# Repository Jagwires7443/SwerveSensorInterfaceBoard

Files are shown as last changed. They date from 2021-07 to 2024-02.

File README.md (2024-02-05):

# SwerveSensorInterfaceBoard
Board to Interface an SRX MAG ENCODER to a SPARK MAX and a roboRIO

This small board (2.0" x 0.7") interfaces an SRX MAG ENCODER to a SPARK MAX (A/B incremental encoder inputs plus PWM absolute encoder input, although the latter is not yet supported by SPARK MAX) and to the roboRIO (PWM absolute encoder input used with a digital input; in software used with DutyCycle or DutyCycleEncoder).  The sensor is powered by the motor controller, and the roboRIO is properly isolated.  This is a good starting point for similar interface projects in the FRC (FIRST Robotics Competition) ecosystem.

These are the [KiCad](https://www.kicad.org/) design files, including schematic symbols, PCB footprints, and 3-D models for all the components.

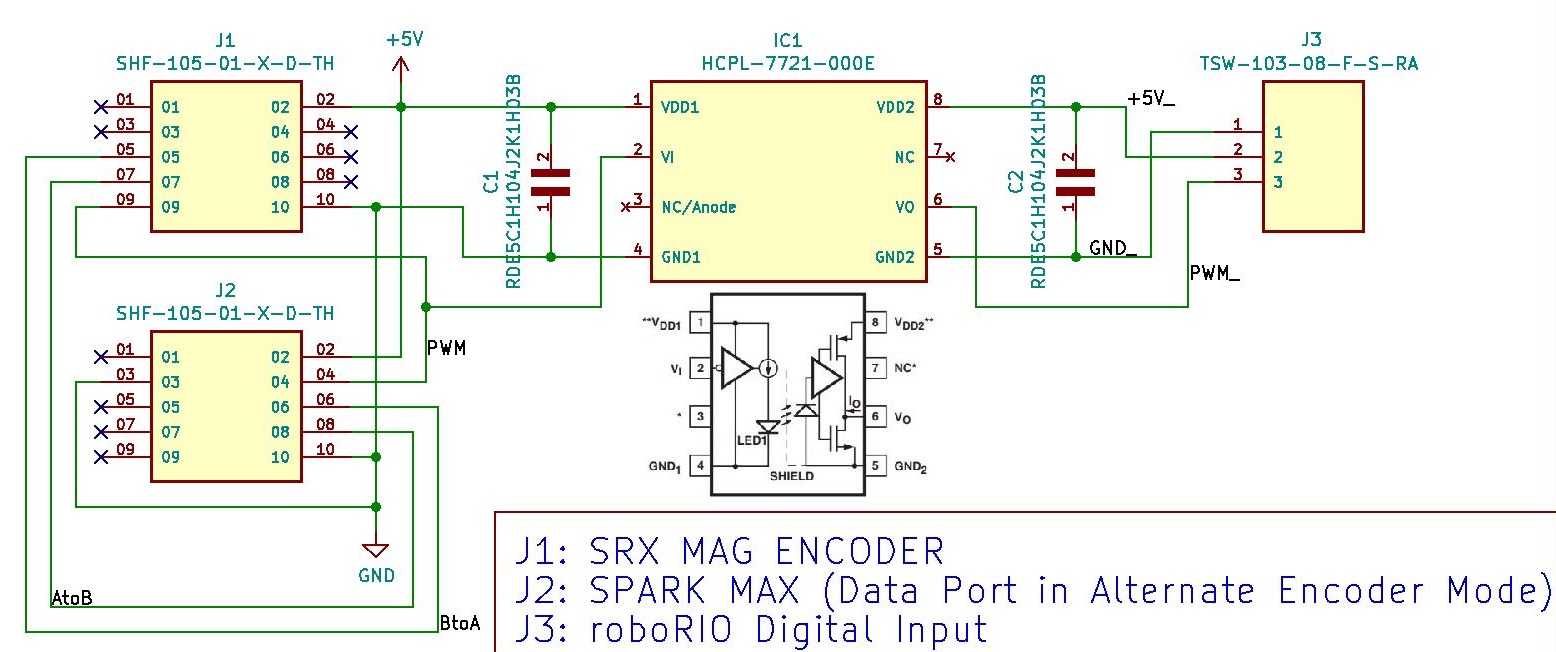
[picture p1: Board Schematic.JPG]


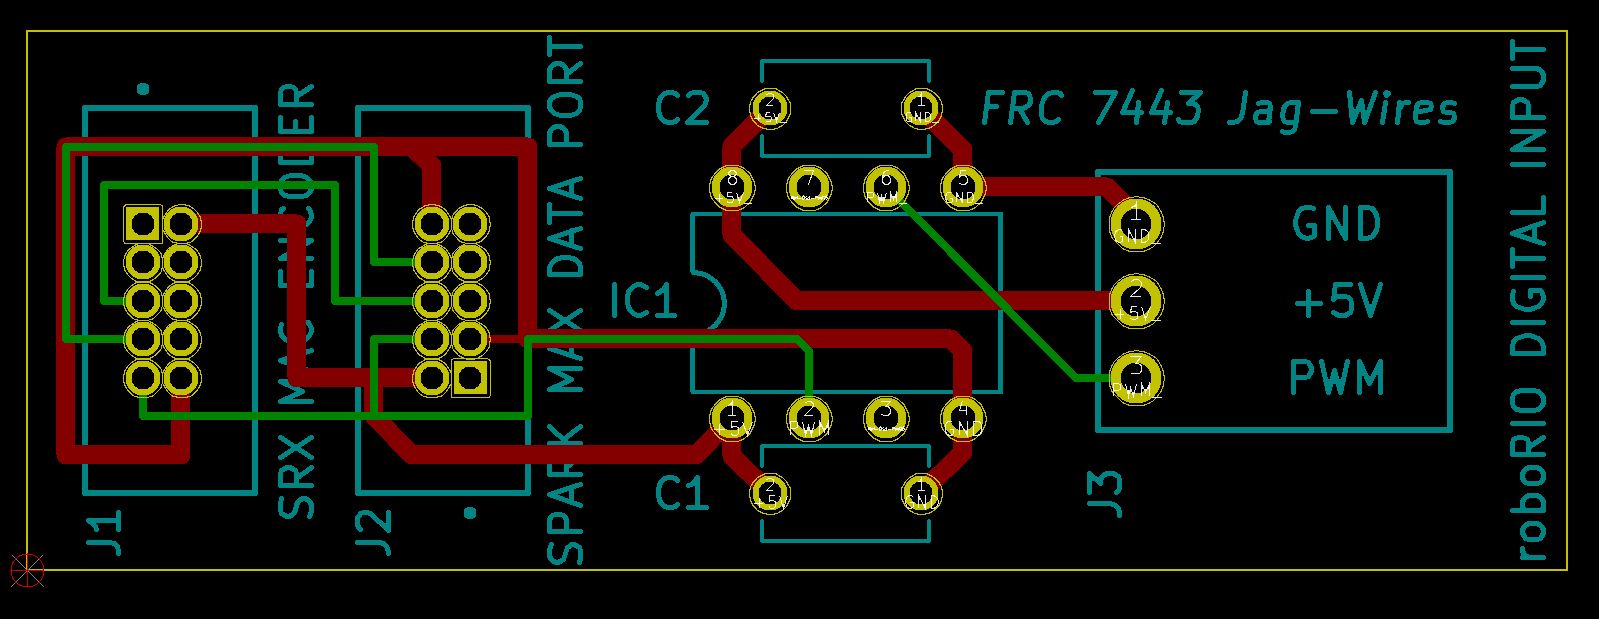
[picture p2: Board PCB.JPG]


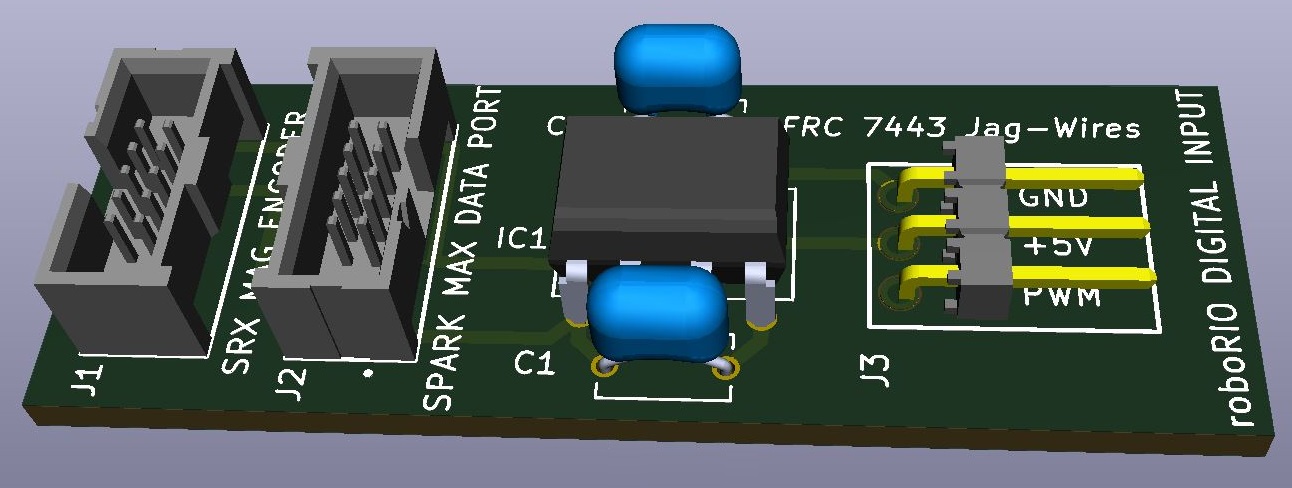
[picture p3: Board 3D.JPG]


***Note that a simpler way to handle this is to leave the SPARK MAX out of things and to simply connect pins 2 (+5V), 9 (PWM), and 10 (GND) from the SRX MAG ENCODER to a roboRIO digital input.  Indeed, until REV addresses [this](https://trello.com/c/bvnPPcZD/108-add-continuous-pid-capability) bug (fixed for 2023), there's not much point in trying to use the SPARK MAX to directly handle closed-loop control.  Here are links to parts (multiple suppliers) that are helpful with this approach:
[CABLE ASSEM .05" 10POS 3"](https://www.digikey.com/en/products/detail/samtec-inc/FFSD-05-D-03-00-01-N/2651110),
[10-pin 2x5 Socket-Socket 1.27mm IDC (SWD) Cable - 150mm long](https://www.adafruit.com/product/1675),
[SRX / Gadgeteer Data Cable (4-pack)](https://newsite.ctr-electronics.com/srx-gadgeteer-data-cable-4-pack/),
[Talon SRX / Spark Max - 10 Pin Data Cable](https://www.andymark.com/products/talon-srx-hero-10-pin-data-cable),
[SWD (2x5 1.27mm) Cable Breakout Board](https://www.adafruit.com/product/2743),
[Gadgeteer Breakout Module (5 Pack)](https://newsite.ctr-electronics.com/gadgeteer-breakout-module-5-pack/),
[SPARK MAX Data Port Breakout Board](https://www.revrobotics.com/rev-11-1278/).***

***Also note that REV now uses pin 6 of the SPARK MAX data port for the PWM absolute encoder input, so this part of the PCB desgn is also out-of-date.***

Working with the 0.05" headers and fine-pitch cables can be tough.  Test that the motor runs as expected before connecting to the SPARK MAX.  Then, be sure the SPARK MAX has been configured to "Alternate Encoder Mode" and this configuration has been saved.  At this point, connect to the SPARK MAX and verify that the LED on the SRX MAG ENCODER is on (any color, the color only depends on the distance to the magnet).  Be sure the LEDs on the SPARK MAX are as expected, and that you can still communicate with it via "REV Hardware Client".  If not, power down and start looking for shorts or opens -- likely trouble spots are the solder connections on the board and the points where the connectors and cables join.  At this point, power and ground are probably good.

Now, check that the motor still runs as expected.  It is possible to short signals which are essential for the motor to run, so suspect a problem in this area if the motor no longer runs well.  Even though these signals normally come in via the built-in signal cable from the (NEO) motor, these same connections are present at the "Data Port".  Trouble in this area may also cause a "Sensor Fault".  If things are all good so far, you can run the motor and should see changing values returned via GetPosition() and GetVelocity().  Finally, check the PWM absolute position signal using a DutyCycle object.  Code to do these things is [here](https://github.com/Jagwires7443/Swerve).  This code contains an extensive test mode (used with Shuffleboard) which will read and display all of the sensor data.

Another option for this type of board is to go surface mount.  The boards REV itself has created seem to use an [FLE-107-01-G-DV](https://www.samtec.com/products/fle-107-01-g-dv-a-tr) connector to directly plug into the SPARK MAX.  Note this is actually a 14-pin connector -- the outer 4 pins are not used to make a connection, but to help to take up some of the excess space on each side of the 10 pins on the connector that is part of the SPARK MAX.  The REV boards are shaped to match the outline of the end of the SPARK MAX where they plug in (roughly 1.16" wide by 0.75" to 0.90" tall, with a roughtly 0.14" by 0.25" notch on each side, roughly 0.14" from the top, with the connector centered roughly 0.18" below the bottom of the notch).

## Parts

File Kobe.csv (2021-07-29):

Quantity | Link | Designator(s) | Manufacturer | Part # | Supplier 1 | Part # | Supplier 2 | Part #
2 | https://www.samtec.com/products/shf-105-01-l-d-th | J1/2 | Samtec | SHF-105-01-L-D-TH | DigiKey | SAM10711-ND | Mouser | 200-SHF10501LDTH
2 | https://www.murata.com/en-us/products/productdetail?partno=RDE5C1H104J2K1H03B | C1/2 | Murata | RDE5C1H104J2K1H03B | DigiKey | 490-RDE5C1H104J2K1H03B-ND | Mouser | 81-RDE5C1H104J2K1H3B
1 | https://www.broadcom.com/products/optocouplers/industrial-plastic/digital-optocouplers/high-speed-cmos/hcpl-7721 | IC1 | Broadcom | HCPL-7721-000E | DigiKey | 516-1550-5-ND | Mouser | 630-HCPL-7721-000E
1 | https://www.samtec.com/products/tsw-103-08-f-s-ra | J3 | Samtec | TSW-103-08-F-S-RA | DigiKey |  | Mouser
1 |  | PCB | Custom | - |  | - |  | -
1 | Solder (Roll/Tube)
4 | 10-pin IDC Connector: https://www.samtec.com/products/ffsd-05-01-n |  | Samtec | FFSD-05-01-N | DigiKey | SAM10472-ND | Mouser | 200-FFSD0501N
2 | 10-conductor Ribbon Cable (2 lengths, cut from 1 longer length) |  | CNC Tech | 300-30-10-GR-0250F | DigiKey | 300-30-10-GR-0250F | Arrow | 300-30-10-GR-0250F
2 | 3-pin Molex Connector |  | Molex | 50579003 | DigiKey | WM2801-ND | Mouser | 50579003
6 | Molex Crimp Sockets (for use with connector above) |  | Molex | 16021124 | DigiKey | WM2573-ND | Mouser | 16021124
1 | PWM Cable
 | [Or: 2x premade 10-pin jumpers and 1x premade PWM cable]
1 | Heatshrink |  | 3M | FP-301 1" CR 100' | DigiKey | FP100C-3R0-ND | Mouser | FP-301 1 1/2" CR 100'

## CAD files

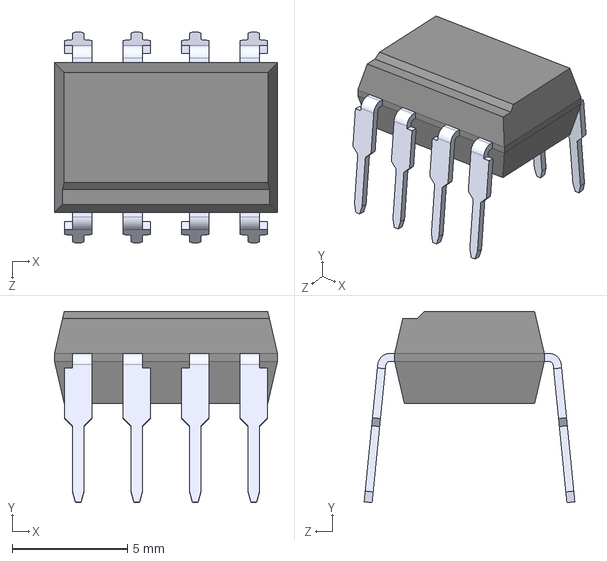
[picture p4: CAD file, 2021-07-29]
HCPL-7721-000E/HCPL-7721-000E.step
9.68 x 8.30 x 9.15 mm

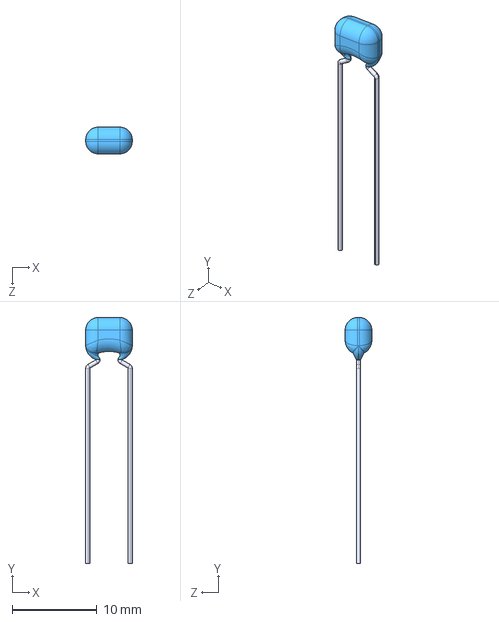
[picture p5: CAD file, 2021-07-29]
RDE5C1H104J2K1H03B/RDE5C1H104J2K1H03B.step
5.50 x 29.0 x 3.15 mm

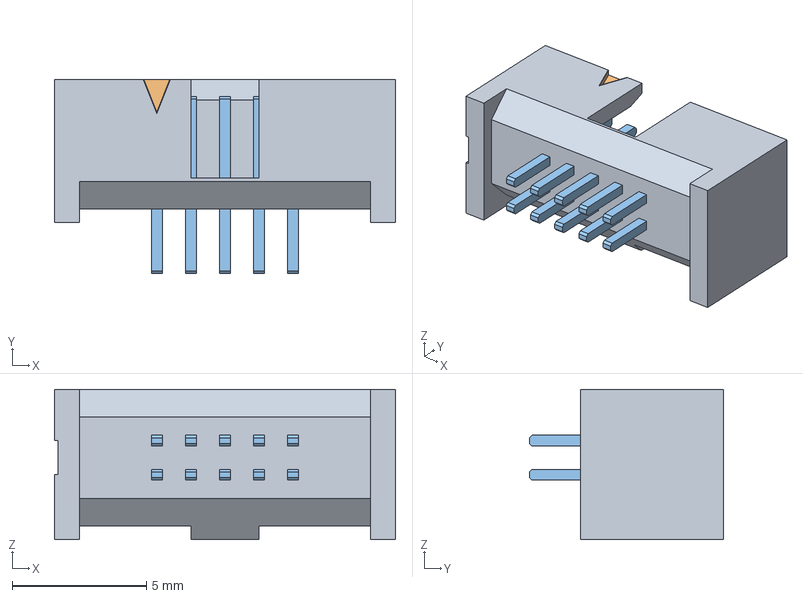
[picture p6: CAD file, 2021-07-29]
SHF-105-01-X-D-TH/SHF-105-01-X-D-TH.step
12.7 x 7.24 x 5.59 mm
_SHF-105-01-D_header
_SHF-First_Position_Indicator
_T-1S71-02-05-D-TH

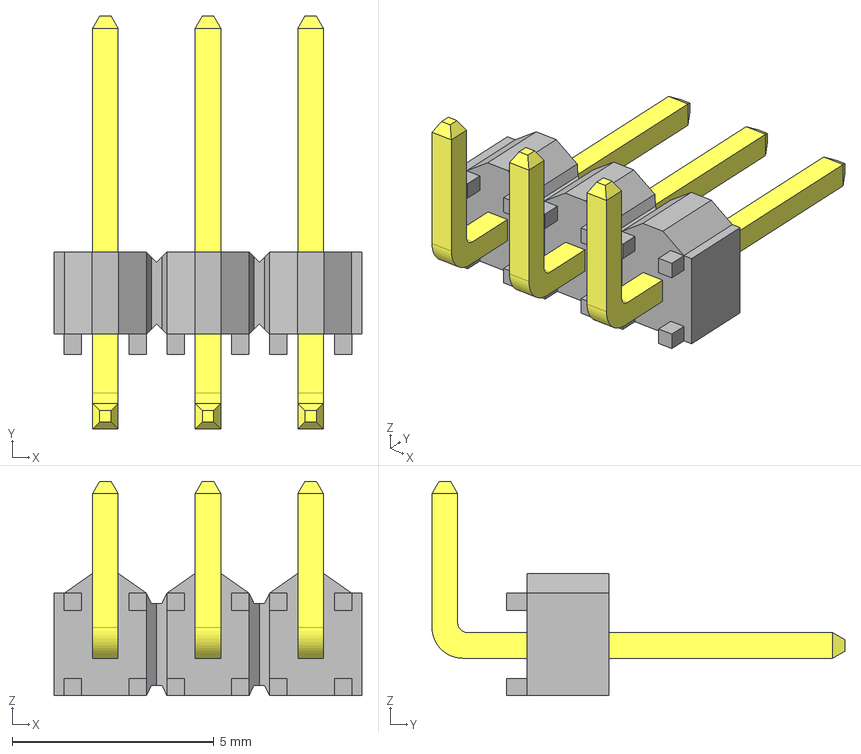
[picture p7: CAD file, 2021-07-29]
TSW-103-08-F-S-RA/TSW-103-08-F-S-RA.step
7.62 x 10.2 x 5.31 mm
_TSW-103-08-F-S-RA_body
_T-1S6-08-TSW-1-08-3-RA-S

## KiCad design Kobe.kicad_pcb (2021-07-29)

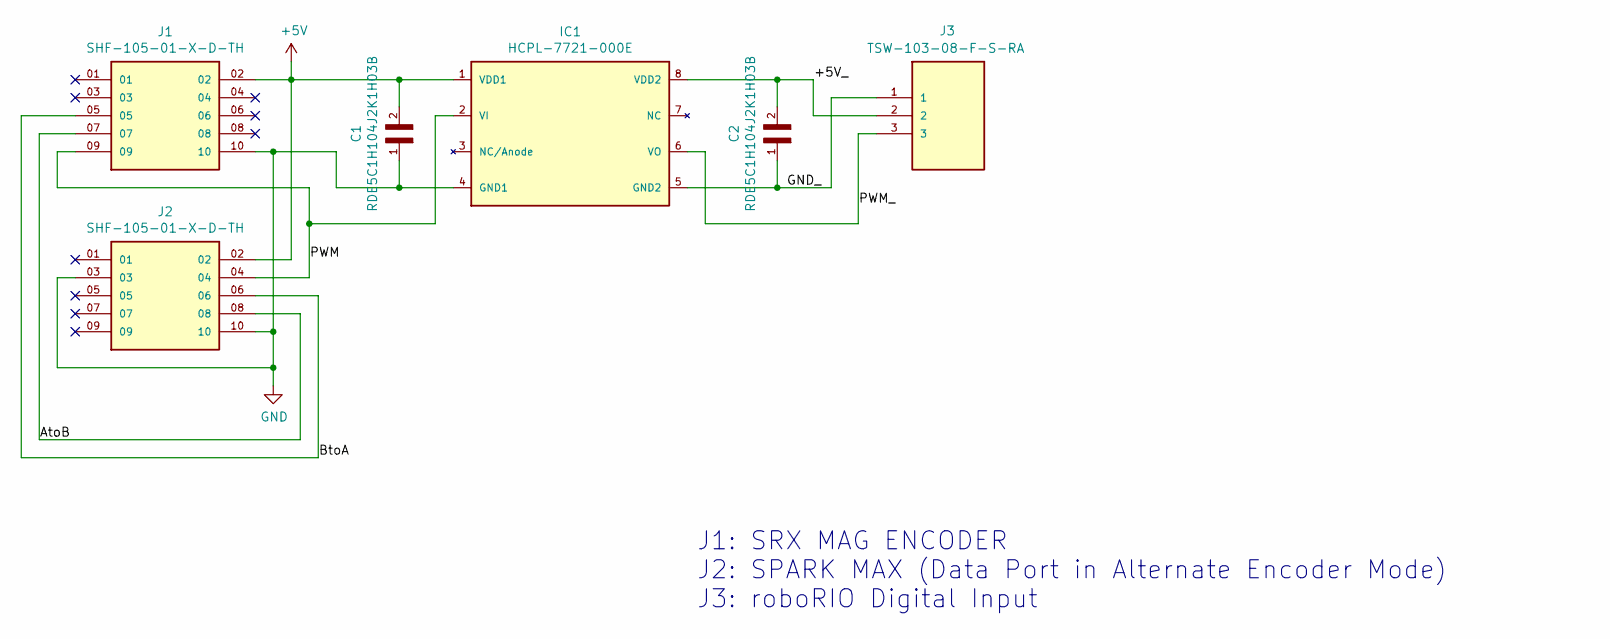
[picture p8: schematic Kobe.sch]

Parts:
C1, C2: RDE5C1H104J2K1H03B; CAP_RDE5C1H104J2K1H03B
IC1: HCPL-7721-000E; DIL08; MPN HCPL-7721-000EA-000E
J1, J2: SHF-105-01-X-D-TH; SAMTEC_SHF-105-01-X-D-TH; PARTREV A
J3: TSW-103-08-F-S-RA

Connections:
+5V: C1.2, IC1.1 (VDD1), J1.02, J2.02
/+5V_: C2.2, IC1.8 (VDD2), J3.2
/AtoB: J1.07, J2.08
/BtoA: J1.05, J2.06
/GND_: C2.1, IC1.5 (GND2), J3.1
/PWM: IC1.2 (VI), J1.09, J2.04
/PWM_: IC1.6 (VO), J3.3
GND: C1.1, IC1.4 (GND1), J1.10, J2.03, J2.10

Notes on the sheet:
J1: SRX MAG ENCODER J2: SPARK MAX (Data Port in Alternate Encoder Mode) J3: roboRIO Digital Input

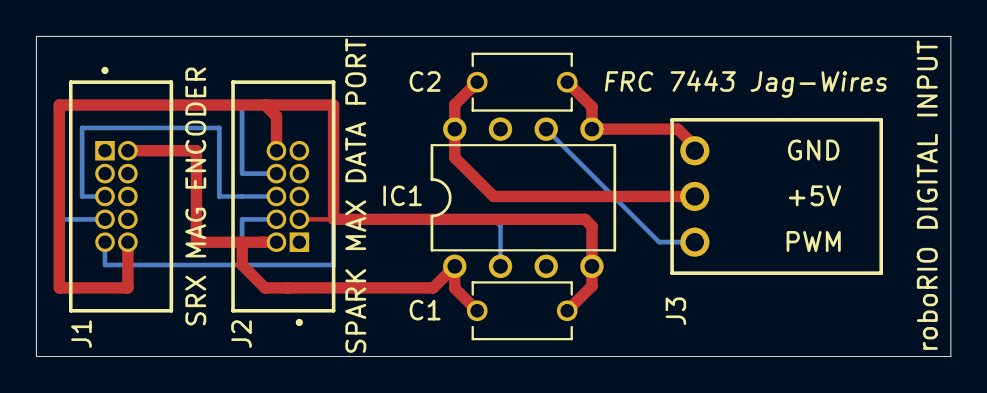
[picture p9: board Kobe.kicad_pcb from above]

Board: 2 copper layers, 50.8 x 17.8 mm, 6 parts (0 on the bottom side), 8 nets.

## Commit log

2021-07-29 Initial Upload
    [Kobe.csv, Kobe.kicad_pcb, Kobe.sch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]
2021-08-06 Update README.md
    Call out an issue in using SPARK MAX for closed-loop control when the A/B encoder needs to wrap around periodically.

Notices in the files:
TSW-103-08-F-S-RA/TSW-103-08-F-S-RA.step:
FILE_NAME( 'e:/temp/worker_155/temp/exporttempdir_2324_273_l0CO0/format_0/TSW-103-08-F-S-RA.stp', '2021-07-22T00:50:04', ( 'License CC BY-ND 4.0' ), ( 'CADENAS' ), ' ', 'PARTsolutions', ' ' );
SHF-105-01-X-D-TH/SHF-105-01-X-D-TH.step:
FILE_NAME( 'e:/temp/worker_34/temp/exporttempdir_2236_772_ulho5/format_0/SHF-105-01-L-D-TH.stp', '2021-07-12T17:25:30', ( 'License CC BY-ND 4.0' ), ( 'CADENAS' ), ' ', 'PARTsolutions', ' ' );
